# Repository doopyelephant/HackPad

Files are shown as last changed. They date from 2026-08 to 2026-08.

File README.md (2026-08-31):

# HackPad
A 16 Key HackPad with a salvaged Touchpad used for swipe gestures, and moving around 3D software, uses QMK Firmware.
## Features:
- 16 Keys
- ELAN Touchpad
- 3D Printed Case
## CAD Model:
It all fits together with 4x M3x16mm screws, one in each corner of the case to connect the bottom to the top, the PCB will just be sandwiched between the bottom and top. There are 2 printed pieces, the "lid" with key holes and bottom.
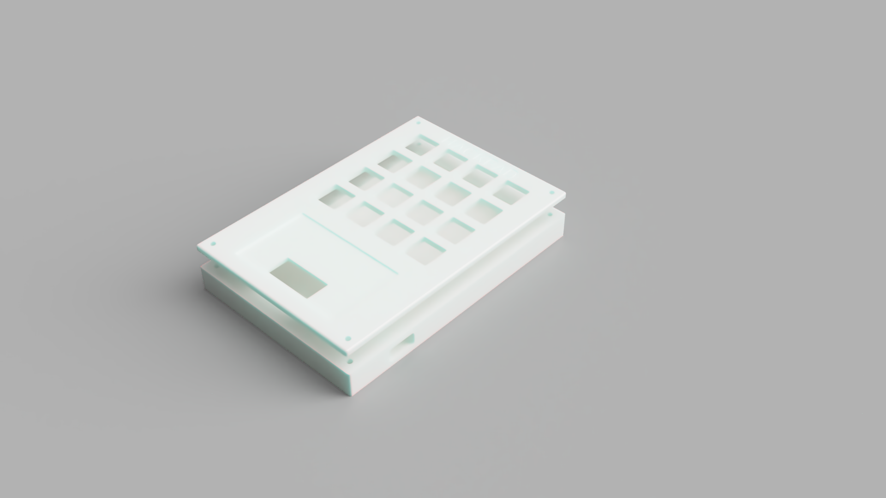
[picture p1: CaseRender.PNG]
Case Render

## PCB:
This is the PCB! It has the microcontroller along with 16 key switches in a matrix. 


Aswell as a place to solder on the 12 pin FFC(Flat Flexible Connecter) that connects to the touchpad. The pinout of the touchpad was reverse engineered with a multimeter and a few partial labels on the donor board, I believe the touchpad uses the PS/2 protocol(the circular mouse port from the 90s) with a few modifications:

-  FFC instead of circular port
- The Two extra pins in the spec are used to relay LB and RB through the touchpad like: LB & RB -> Touchpad -> SOC
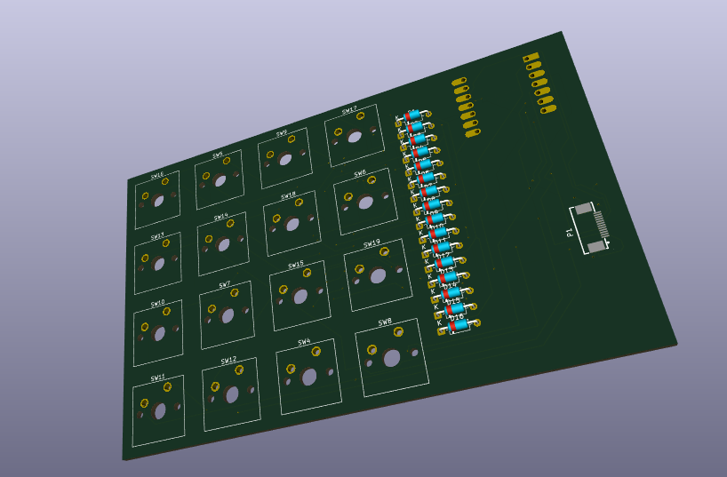
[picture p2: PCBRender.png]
PCB Render

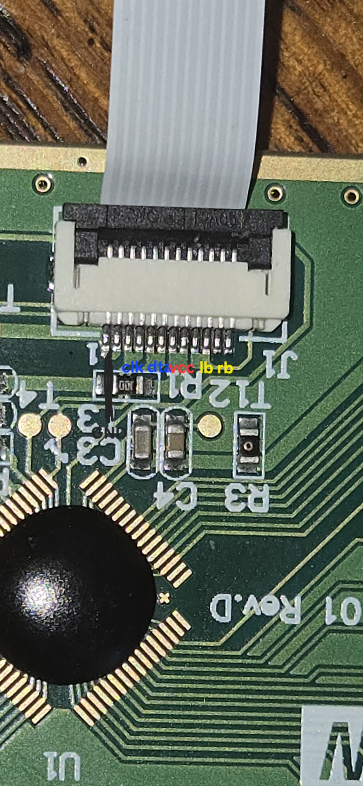
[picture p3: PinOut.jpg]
Pin Out

## Firmware
This Hackpad uses QMK (QMK suprisingly has support for PS/2! )

- Keys can be programmed to whatever, defaults to a numpad
- Touchpad acts as a mouse, planning on making a userspace driver to do more fancy things in the future

Thats it for now!

## BOM:
- 4x M3x16mm screws
- 16x 1N4148 Diodes
- 16x DSA Keycaps
- 16x Cherry MX Switches
- 1x XIAO RP2040
- 1x Case (2 Printed Parts)

  **Already Obtained:**
- 1x 12 pin FFC connector (I salvaged this from the main PCB on the same broken keyboard mentioned below)
- 1x ELAN CK77 Touchpad (I already Salvaged this from a broken keyboard, you might be able to find one to, they are pretty old and are in various things, mine was designed in 2007)
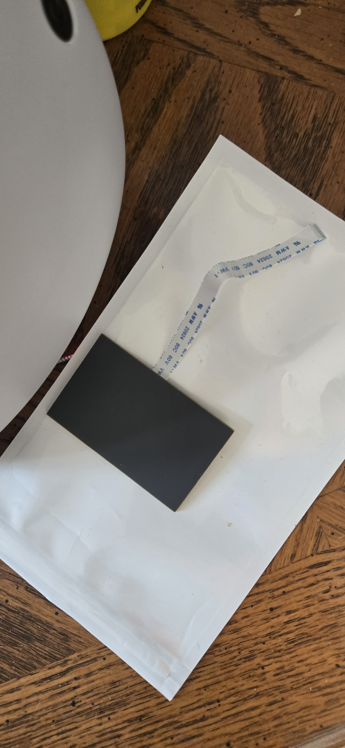
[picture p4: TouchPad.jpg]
TouchPad


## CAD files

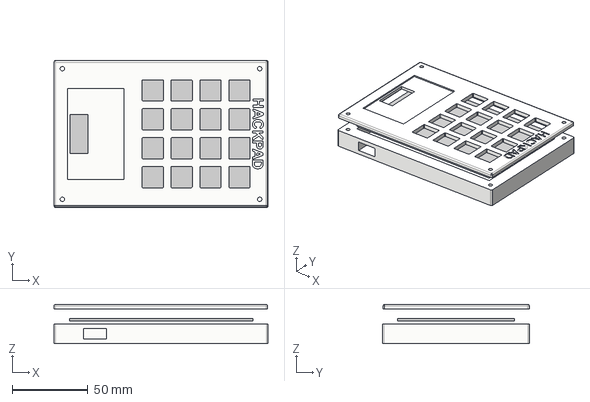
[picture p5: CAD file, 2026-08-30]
CAD/HackPad-CAD.step
140.9 x 96.9 x 26.0 mm

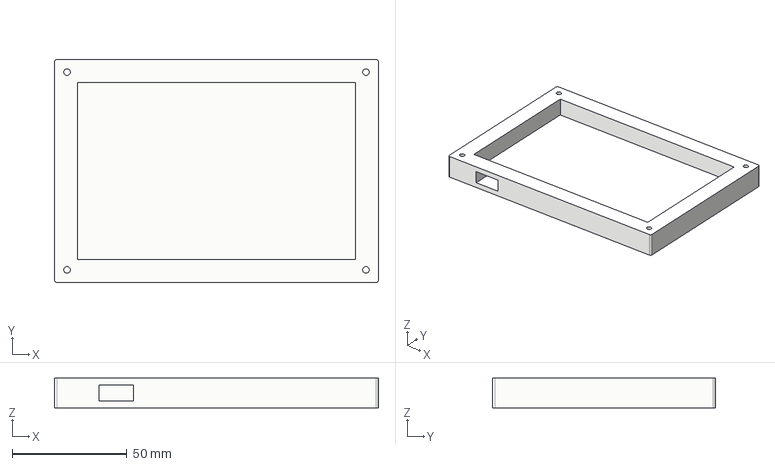
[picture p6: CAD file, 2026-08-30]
Production/HackPad-BOTTOM.step
140.9 x 96.9 x 13.0 mm

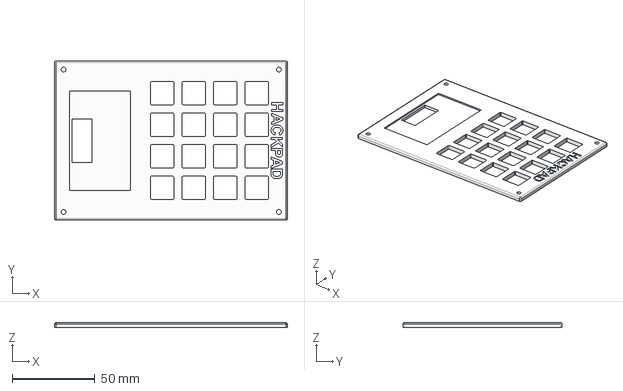
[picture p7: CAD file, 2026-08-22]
Production/HackPad-TOP.step
140.7 x 96.2 x 3.00 mm

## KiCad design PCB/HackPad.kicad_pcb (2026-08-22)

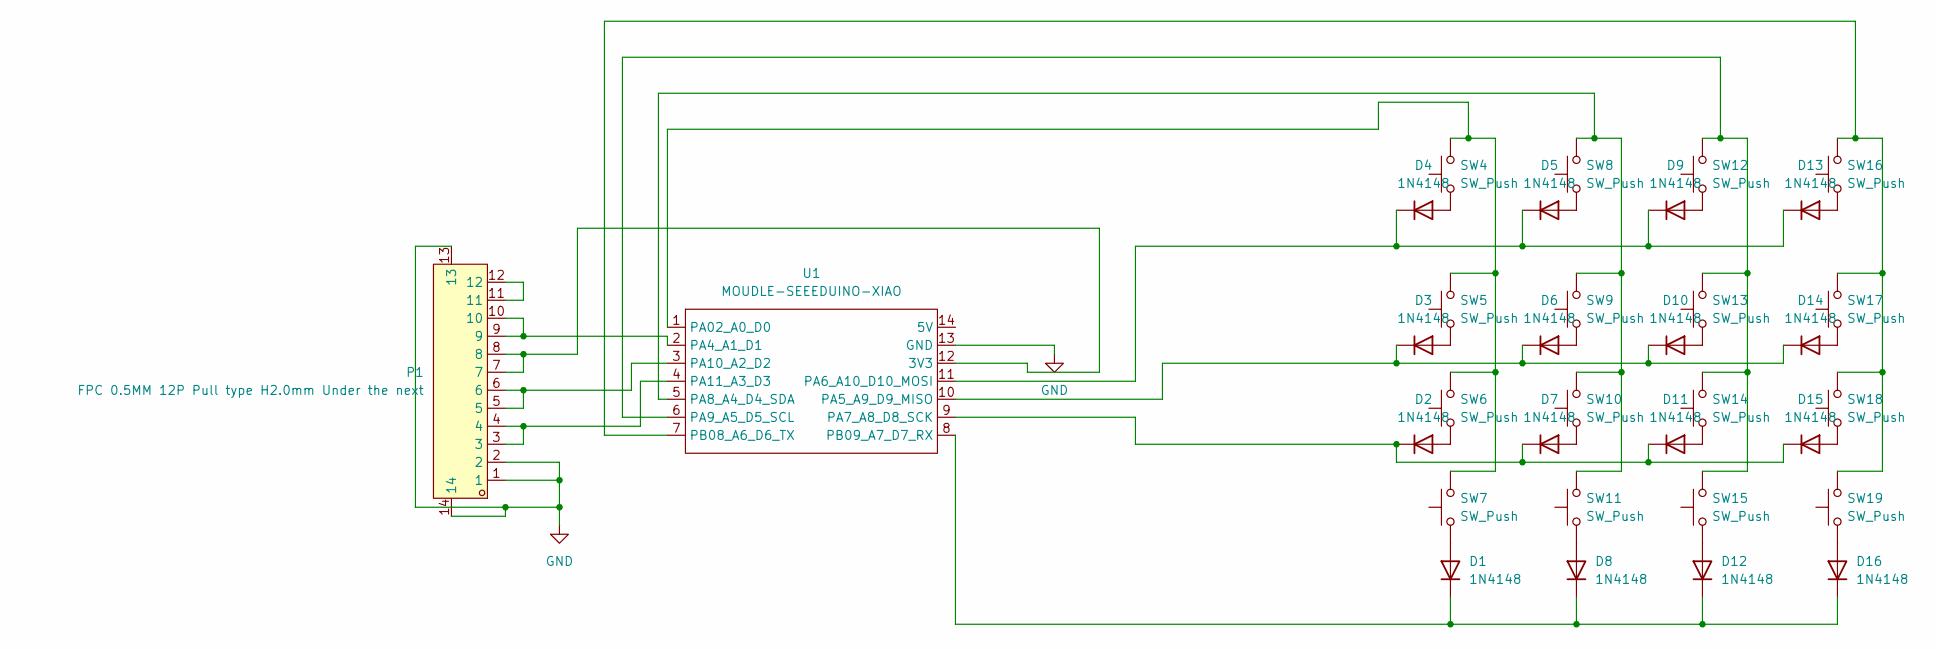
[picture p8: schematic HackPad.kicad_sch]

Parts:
D1, D2, D3, D4, D5, D6, D7, D8, D9, D10, D11, D12, D13, D14, D15, D16: 1N4148; D_DO-35_SOD27_P7.62mm_Horizontal
P1: FPC 0.5MM 12P Pull type H2.0mm Under the next; FPC-SMD_12P-P0.50_AFC07-S12FCC-00; MPN AFC07-S12FCC-00; LCSC Part C11051
SW4, SW5, SW6, SW7, SW8, SW9, SW10, SW11, SW12, SW13, SW14, SW15, SW16, SW17, SW18, SW19: SW_Push; SW_Cherry_MX_1.00u_PCB
U1: MOUDLE-SEEEDUINO-XIAO; XIAO-Generic-Hybrid-14P-2.54-21X17.8MM

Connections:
GND: P1.1, P1.2, P1.13, P1.14, U1.13 (GND)
unnamed: D1.2 (A), SW7.1
unnamed: D1.1 (K), D8.1 (K), D12.1 (K), D16.1 (K), U1.8 (PB09_A7_D7_RX)
unnamed: D2.2 (A), SW6.1
unnamed: D3.2 (A), SW5.1
unnamed: D4.2 (A), SW4.1
unnamed: D5.2 (A), SW8.1
unnamed: D6.2 (A), SW9.1
unnamed: D7.2 (A), SW10.1
unnamed: D8.2 (A), SW11.1
unnamed: D9.2 (A), SW12.1
unnamed: D10.2 (A), SW13.1
unnamed: D3.1 (K), D6.1 (K), D10.1 (K), D14.1 (K), U1.10 (PA5_A9_D9_MISO)
unnamed: D11.2 (A), SW14.1
unnamed: D2.1 (K), D7.1 (K), D11.1 (K), D15.1 (K), U1.9 (PA7_A8_D8_SCK)
unnamed: D12.2 (A), SW15.1
unnamed: D13.2 (A), SW16.1
unnamed: D4.1 (K), D5.1 (K), D9.1 (K), D13.1 (K), U1.11 (PA6_A10_D10_MOSI)
unnamed: D14.2 (A), SW17.1
unnamed: D15.2 (A), SW18.1
unnamed: D16.2 (A), SW19.1
unnamed: P1.11, P1.12
unnamed: P1.7, P1.8, U1.12 (3V3)
unnamed: SW4.2, SW5.2, SW6.2, SW7.2, U1.1 (PA02_A0_D0)
unnamed: P1.9, P1.10, U1.2 (PA4_A1_D1)
unnamed: SW8.2, SW9.2, SW10.2, SW11.2, U1.5 (PA8_A4_D4_SDA)
unnamed: SW12.2, SW13.2, SW14.2, SW15.2, U1.6 (PA9_A5_D5_SCL)
unnamed: P1.5, P1.6, U1.3 (PA10_A2_D2)
unnamed: P1.3, P1.4, U1.4 (PA11_A3_D3)
unnamed: SW16.2, SW17.2, SW18.2, SW19.2, U1.7 (PB08_A6_D6_TX)

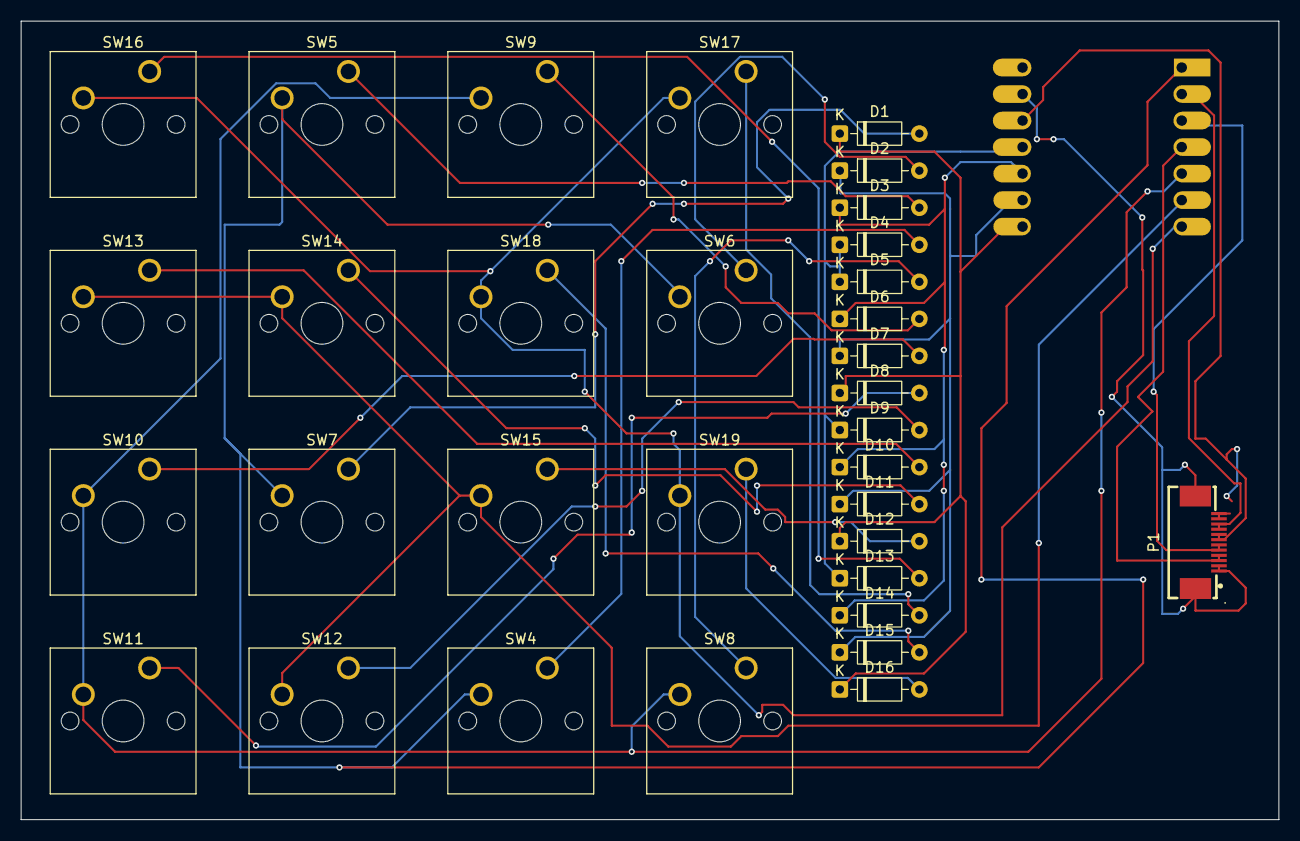
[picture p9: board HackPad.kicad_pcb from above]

Board: 2 copper layers, 120.5 x 76.5 mm, 34 parts (1 on the bottom side), 30 nets.

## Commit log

2026-08-23 Rename Screenshot 2026-08-22 200625.png to PCBRender.png
2026-08-30 Renamed Firmware file and added more padding with no rounded corners on case usb hole
    [HackPad-BOTTOM.step, HackPad-CAD.step]
2026-08-31 Add PCB Design Screenshot
